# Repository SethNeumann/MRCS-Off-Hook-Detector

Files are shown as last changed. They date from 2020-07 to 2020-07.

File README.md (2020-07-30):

# REPO NAME: MRCS-Off-Hook-Detector
## License: Creative Commons Attribution-NonCommercial-ShareAlike

Provides a contact closure when phone goes off hook

intial version

The published project on the SPCoast.github.io website will
include the relevant git commit messages as a terse, high level
changelog, so don't replicate those messages here.

Many circuits used in telephony depend on knowing the state of a telephone station: whether it is on-hook or off-hook.  
Telephone people refer to this as “supervision” or in context of business telephone systems “A Lead Control.”  
In traditional office telephone systems, the “A lead” is grounded when the associated line appearance is in use.  
This ground is used to light a lamp and for control of the HOLD state.  
For model railroad telephone systems, the A lead is used to stop ringing or buzzing when a station is answered (goes off hook) 
and may be used for a busy station display where a LED or lamp lights when the associated phone is off-hook.  
Normally, when using classic telephones such as 500/554 desk and wall sets, we borrow one of the hook-switch contacts to provide an A lead.  
However not all telephones have an extra hook-switch contact, some consumer phones 
(including some retro decorator phones that have a nice transition-era look) are sealed and contacts are inaccessible 
and sometimes extra conductors are not available in the cable to the telephone.  
In those cases, it is useful to have a device which looks for current drawn on the telephone line itself and reports status accordingly 
(somewhat like a track occupancy detector).  This is the Off-Hook Detector.

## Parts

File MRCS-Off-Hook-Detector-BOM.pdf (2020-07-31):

Off Hook Detector

Qty | Value | Device | Package | Parts | Description
2 1000 uF@16 | CPOL-USE3.5-8 | E3,5-8 | C1, C2 | POLARIZED CAPACITOR, American symbol
1 | 12V | CONNECTOR-DC-POWER-RA | DCJ0202 | CON7 | DC POWER JACK
5 1N4001 | DIODEPTH | DIODE-1N4001 | D1, D2, D3, D4, D5 Diode
1 | 1N5819 | DIODEPTH | DIODE-1N5819 | D6 | Diode
1 22 | RPTH04 | AXIAL-0.4-RES | R1 | Resistor
2 | Ground COM1 | JUMPER-2PTH | 1X02 | JP1, JP2 | Ground Jumper
1 CON3 | JUMPER-3PTH | 1X03 | CON9 (really JP3) | jumper for A lead polarity
1 | H11AA1 | H11AA1 | DIP762W50P254L730H410Q6 | U1 | Optoisolator Transistor with Base Output 5300Vrms 1 Channel 6-DIP
2 Line | CONNECTOR-M06LOCK | 1X06_LOCK | CON3,4 | Header 6 Standard 6-pin 0.1 header"
2 | Line | CONNECTOR-RJ25-43860-2-MOLEX | RJ25-INVERTED | CON1, CON2 | AMP connector
1 RELAY-G5v2 | RELAY-G2R2 | G2R2 | K1 | RELAY
1 | Circuit Board | | | | Circuit Board
3 0.100 jumper
Page 1 of 1 | 7/31/2020

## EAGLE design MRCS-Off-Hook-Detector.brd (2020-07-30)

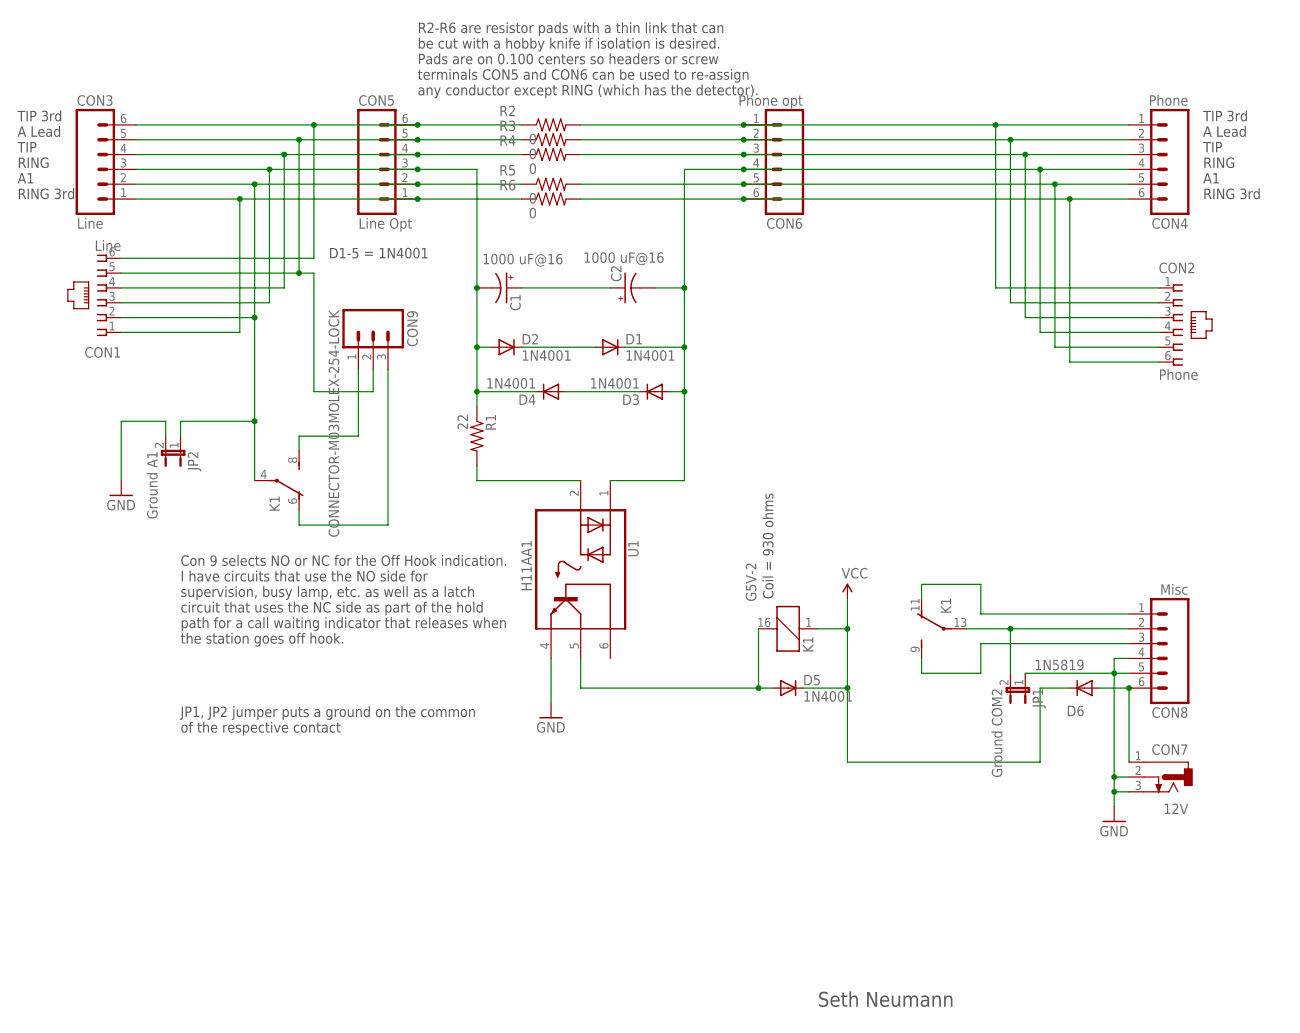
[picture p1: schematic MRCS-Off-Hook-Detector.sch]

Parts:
C1, C2: 1000 uF@16; E3,5-8
CON1: Line; RJ25-INVERTED
CON2: Phone; RJ25-INVERTED
CON3: Line; 1X06_LOCK
CON4: Phone; 1X06_LOCK
CON5: Line Opt; 1X06_LOCK
CON6: Phone opt; 1X06_LOCK
CON7: 12V; DCJ0202
CON8: Misc; 1X06_LOCK
CON9: CONNECTOR-M03MOLEX-254-LOCK; MOLEX-1X3_LOCK
D1, D2, D3, D4, D5: 1N4001; DIODE-1N4001
D6: 1N5819; DIODE-1N4001
JP1: Ground COM2; 1X02
JP2: Ground A1; 1X02
K1: G5V-2
R1: 22; AXIAL-0.4-RES
R2, R3, R4, R5, R6: 0; CUT-R
U1: H11AA1; DIP762W50P254L730H410Q6

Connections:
3RL: CON1.1, CON3.1, CON5.1, R6.P2 (1)
3RS: CON2.6, CON4.6, CON6.6, R6.P1 (2)
3TL: CON1.6, CON3.6, CON5.6, R2.P2 (1)
3TS: CON2.1, CON4.1, CON6.1, R2.P1 (2)
+12: CON7.1, CON8.6, D6.A
A1_LINE: CON1.2, CON3.2, CON5.2, JP2.1, K1.4, R5.P2 (1)
A1_PHONE: CON2.5, CON4.5, CON6.5, R5.P1 (2)
A_LINE: CON1.5, CON3.5, CON5.5, CON9.2, R3.P2 (1)
A_PHONE: CON2.2, CON4.2, CON6.2, R3.P1 (2)
GND: CON7.2, CON7.3, CON8.4, CON8.5, JP1.1, JP2.2, U1.4 (E)
unnamed: D5.A, K1.16 (2), U1.5 (C)
unnamed: R1.P$2 (2), U1.2 (C/A)
unnamed: CON8.1, K1.11 (O)
unnamed: D1.A, D2.C
unnamed: C1.+, C2.+
unnamed: D3.C, D4.A
unnamed: CON9.1, K1.8 (S)
unnamed: CON9.3, K1.6 (O)
unnamed: CON8.2, JP1.2, K1.13
unnamed: CON8.3, K1.9 (S)
RING-PHONE: C2.-, CON2.4, CON4.4, CON6.4, D1.C, D3.A, U1.1 (A/C)
RING_LINE: C1.-, CON1.3, CON3.3, CON5.3, D2.A, D4.C, R1.P$1 (1)
TIP_LINE: CON1.4, CON3.4, CON5.4, R4.P2 (1)
TIP_PHONE: CON2.3, CON4.3, CON6.3, R4.P1 (2)
VCC: D5.C, D6.C, K1.1

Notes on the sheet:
D1-5 = 1N4001
Coil = 930 ohms
Con 9 selects NO or NC for the Off Hook indication. I have circuits that use the NO side for supervision, busy lamp, etc. as well as a latch circuit that uses the NC side as part of the hold path for a call waiting indicator that releases when the station goes off hook.
R2-R6 are resistor pads with a thin link that can be cut with a hobby knife if isolation is desired. Pads are on 0.100 centers so headers or screw terminals CON5 and CON6 can be used to re-assign any conductor except RING (which has the detector).
JP1, JP2 jumper puts a ground on the common of the respective contact
TIP 3rd A Lead TIP RING A1 RING 3rd
Seth Neumann

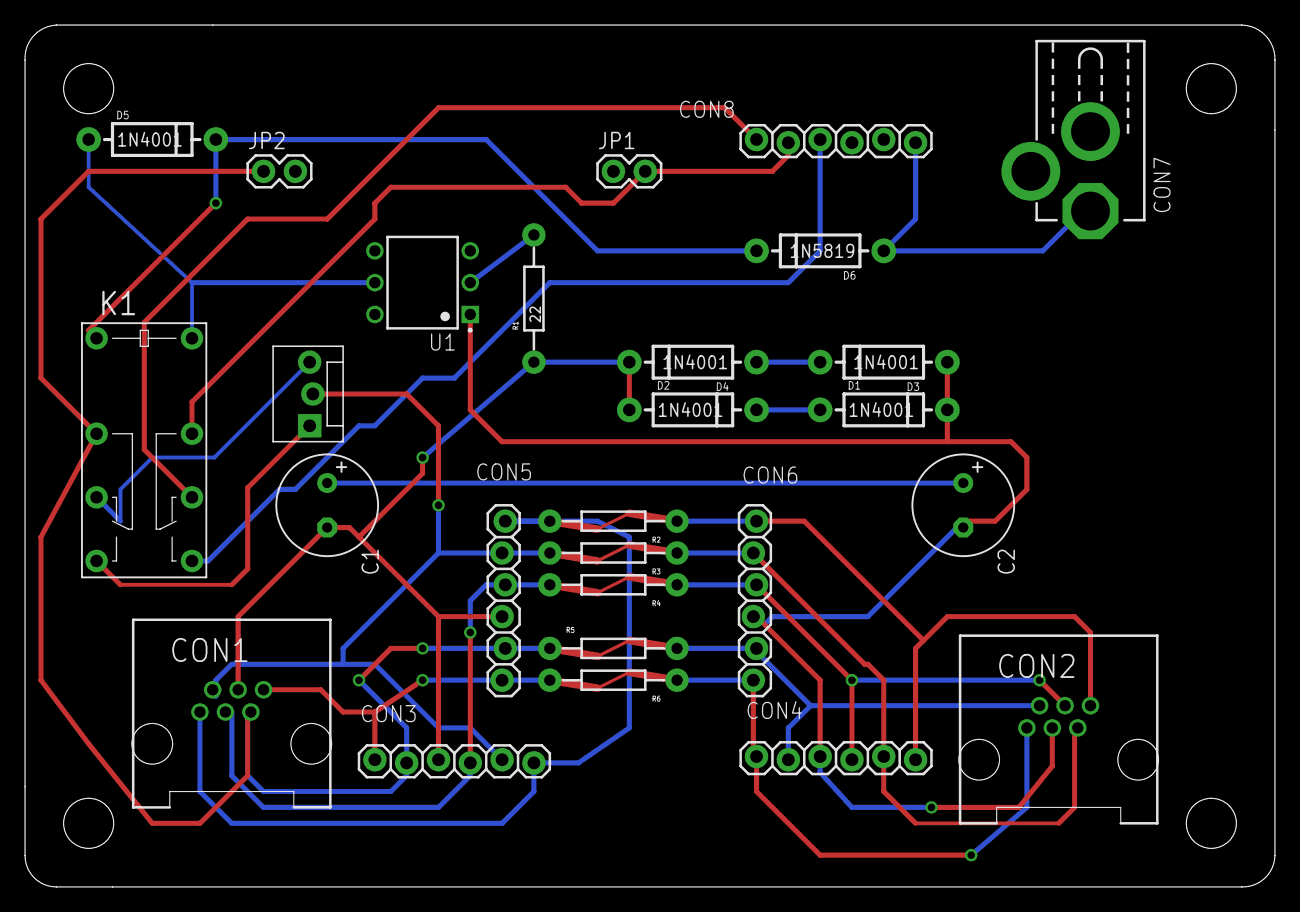
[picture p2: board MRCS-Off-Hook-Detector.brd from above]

Board: 2 copper layers, 99.8 x 68.8 mm, 32 parts (0 on the bottom side), 25 nets.

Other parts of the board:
U$1: BOARD-DINRAIL-2.7IN
U$2: CA-PROP65WARNING
U$3: MRCSLOGOBTM
U$4, U$5: MRCSLOGOTOP

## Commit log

2020-07-30 git hub setting up
    [EagleTemplate-new.brd, EagleTemplate-new.sch]
2020-07-30 copying new files from old directory
    [MRCS-Off-Hook-Detector.brd, MRCS-Off-Hook-Detector.sch]
2020-07-31 add BOM to git

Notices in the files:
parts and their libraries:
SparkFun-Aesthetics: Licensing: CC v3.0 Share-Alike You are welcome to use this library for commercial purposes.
